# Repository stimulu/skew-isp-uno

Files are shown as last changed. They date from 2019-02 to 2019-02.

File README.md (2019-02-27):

# Skew ISP Uno

40084f455e98bf24bbd68a4dbfa840b0

[Order the PCB on OSH Park](https://oshpark.com/shared_projects/m8nYVVg6)

### Features
Skew ISP Uno is an ISP programming shield for Arduino Uno.  
Use it with the sketch described at [Arduino.cc's Arduino ISP Tutorial](https://www.arduino.cc/en/Tutorial/ArduinoISP#toc5).   
This shield enables programming of AVR chips notably ATTiny or ATMega.  
One special feature is the presence of a 6 positions Molex PicoBlade connector.

This board features slots for:

* ATTiny ×4
* ATTiny ×5
* a 2×3 pins ISP port
* a 6 pins Molex PicoBlade

### BOM

##### Required 

* 1 × capacitor 10µF ([Digikey 1572-1289-ND](https://www.digikey.com/products/en?keywords=1572-1289-ND))
* 4 + 7 positions connector header 2.54mm pitch ([Digikey 609-5133-ND](https://www.digikey.com/products/en?keywords=609-5133-ND))

##### Optional 
* 1 × connector header 6 positions 2.54mm pitch ([Digikey 609-3234-ND](https://www.digikey.com/products/en?keywords=609-3234-ND))
* 1 × IC socket 8 positions 2.54mm pitch ([Digikey 2057-ICS-308-T-ND](https://www.digikey.com/products/en?keywords=2057-ICS-308-T-ND))
* 1 × IC socket 14 positions 2.54mm pitch ([Digikey AE9989-ND](https://www.digikey.com/products/en?keywords=AE9989-ND))
* 1 × Molex PicoBlade connector header 6 positions ([Digikey WM1735-ND](https://www.digikey.com/products/en?keywords=WM1735-ND))
* 1 × Molex PicoBlade cable assembly 6 positions ([Digikey WM15267-ND](https://www.digikey.com/products/en?keywords=WM15267-ND))
* 2 × 200 ohm 0805 SMD resistor ([Digikey 311-200CRCT-ND](https://www.digikey.com/products/en?keywords=311-200CRCT-ND))
* 2 × red LED 0603 ([Digikey 732-4978-1-ND](https://www.digikey.com/products/en?keywords=732-4978-1-ND))

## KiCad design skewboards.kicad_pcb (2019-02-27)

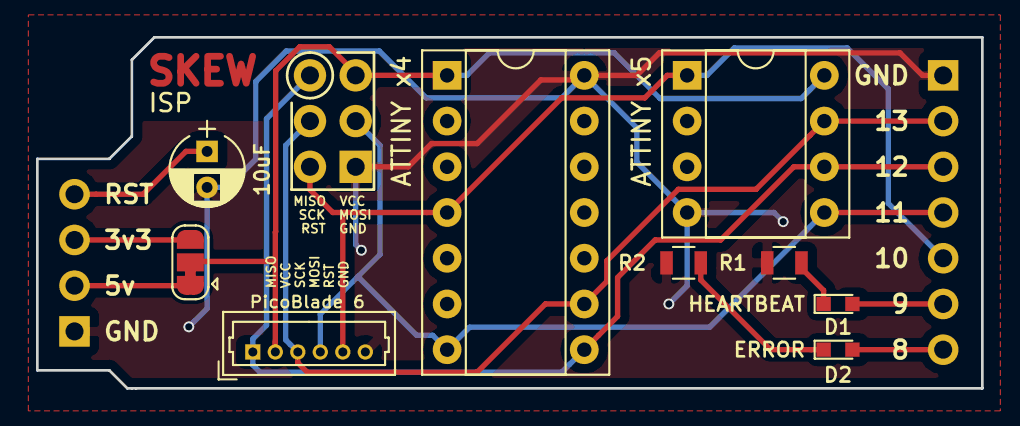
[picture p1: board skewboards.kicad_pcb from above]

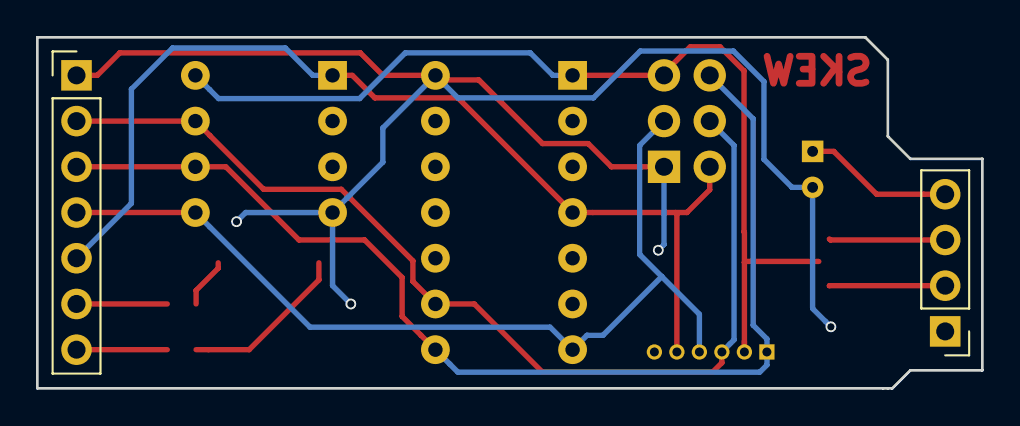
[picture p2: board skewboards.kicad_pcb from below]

Board: 2 copper layers, 52.5 x 19.5 mm, 12 parts (2 on the bottom side), 13 nets.

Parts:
C1: 10uF; CP_Radial_D4.0mm_P2.00mm
D1: HEARTBEAT; LED_0603
D2: ERROR; LED_0603
J1: UNO POWER; Pin_Header_Straight_1x04_Pitch2.54mm
J2: UNO PIN 8-13, GND; Pin_Header_Straight_1x07_Pitch2.54mm
J4: ICSP_header; ICSP_th
J5: microblade 6; Molex_PicoBlade_53047-0610_06x1.25mm_Straight
JP1: Jumper_3_Bridged12; SolderJumper-3_P1.3mm_Bridged12_RoundedPad1.0x1.5mm
R1, R2: R; R_0805
S8: ATTINY x5; DIP-8_W7.62mm_Socket
S14: ATTINY x4; DIP-14_W7.62mm_Socket

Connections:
/ERROR: D2.2, J2.7
/HEARTBEAT: D1.2, J2.6
/MISO: J2.3, J4.1, J5.1, S8.6, S14.8
/MOSI: J2.4, J4.4, J5.4, S8.5, S14.7
/RESET: J2.5, J4.5, J5.5, S8.1, S14.4
/RST: C1.1, J1.4
/SCK: J2.2, J4.3, J5.3, S8.7, S14.9
GND: C1.2, J1.1, J2.1, J4.6, J5.6, R1.2, R2.2, S8.4, S14.14
unnamed: D1.1, R1.1
unnamed: D2.1, R2.1
unnamed: J1.2, JP1.1
unnamed: J1.3, JP1.3
VCC: J4.2, J5.2, JP1.2, S8.8, S14.1

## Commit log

2019-02-27 Init with existing files
    [skewboards.kicad_pcb, skewboards.sch]
2019-03-01 Add interactiv BOM
2019-03-01 Add Gerbers
    [skewboards-B.Cu.gbl, skewboards-B.Mask.gbs, skewboards-B.Paste.gbp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]
